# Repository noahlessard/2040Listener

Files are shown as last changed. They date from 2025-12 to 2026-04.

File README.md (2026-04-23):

## 2040Listener

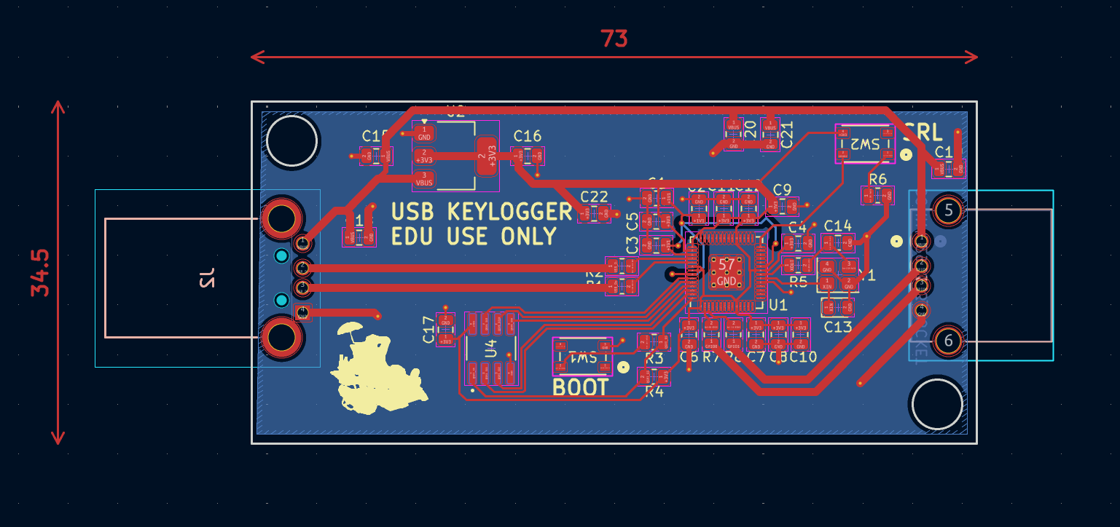
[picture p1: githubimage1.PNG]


This project contains the Raspberry Pi Pico C SDK Project, and Kicad PCB Project, to manufacture an open source MITM style keystroke interceptor. This style of device intercepts a host's computer request to get keystrokes, relays it to a real USB keyboard, and while returning the responses of typed keys, logs it to a LittleFS file stored in flash memory. This memory persists, and can be accessed through a CDC serial port. This port can be toggled on/off for a "stealth" mode.

USB host/device communication is done using the PIO of Raspberry Pi Pico (RP2040). I built the software with the VSCode Pico Project Extension. It uses several other open source libraries, which can be found in the credits section at the bottom of this readme. 

The PCB is designed around the 0805 footprint for easier soldering, and a simple 2 layer board for cheaper manufacturing.

The general idea of the firmware architecture is that core0 of the 2040 acts as a "fake" USB device to the victim computer, sending both HID and CDC data over USB. Core1 acts as a "fake" host stack to a keyboard. Core1 handles getting data from the HID devices, parsing out what the keystroke is and writes to the 2040's LittleFS file before core0 actually transmits. For more details, see my blog post: https://nlessard.online/projects/2040listener/.

**If you decide to build this device yourself, please use it for educational purposes only, and never use it on a computer that you don't control!**

## GPIO 
(This section is useful for testing on a normal Pico board, where access to GP pins is easier.)
|VCC|VBUS|
|-|-|
|D-|GP 1|
|D+|GP 0|
|CNC Toggle|GP 17|
|Ground|GND|

## Credits
Dual host + device listener example from here: https://github.com/brendena/pico_device_and_host, although I used a fork for the Pico VS Code extension: https://github.com/TheLowSpecPC/pico_device_and_host_updated. LittleFS was ported to Pico in this library: https://github.com/tjko/pico-lfs. I used the Raspberry Pi's foundation for a lot of advice during hardware design: https://pip-assets.raspberrypi.com/categories/814-rp2040/documents/RP-008279-DS-1-hardware-design-with-rp2040.pdf

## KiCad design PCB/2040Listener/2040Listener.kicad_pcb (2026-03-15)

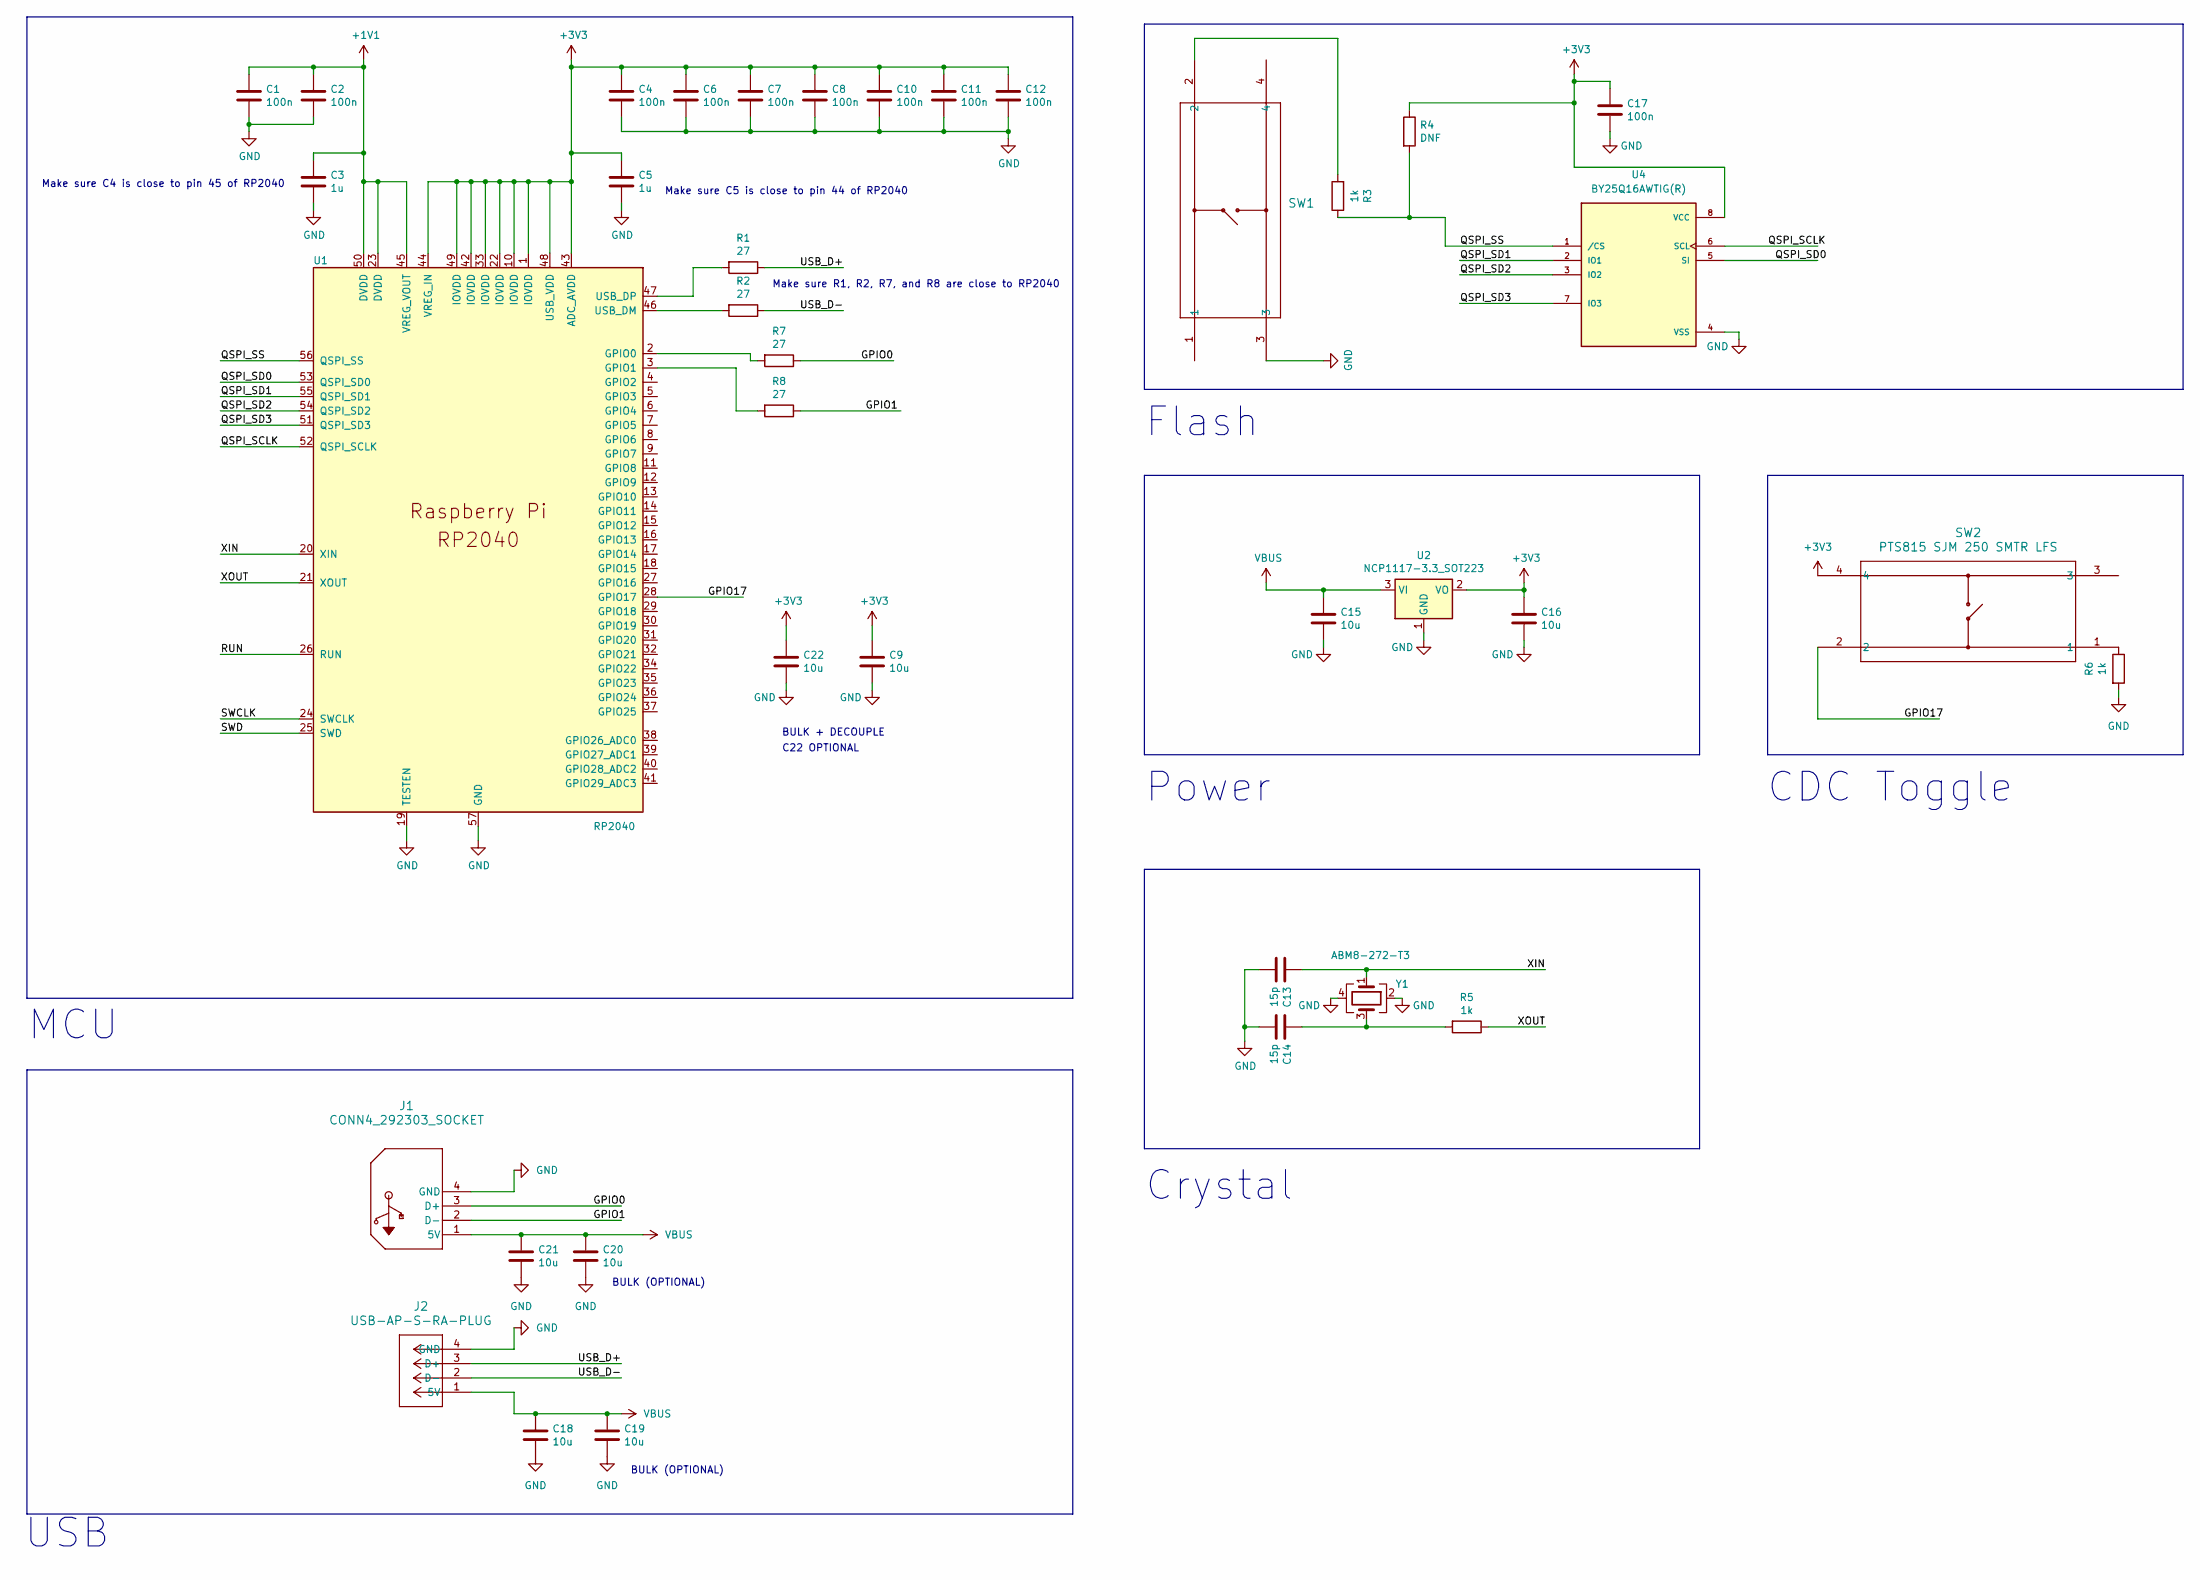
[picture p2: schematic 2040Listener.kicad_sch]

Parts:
C1, C2, C4, C6, C7, C8, C10, C11, C12, C17: 100n; C_0805_2012Metric
C3, C5: 1u; C_0805_2012Metric
C9, C15, C16, C18, C19, C20, C21, C22: 10u; C_0805_2012Metric
C13: 15p; D_0805_2012Metric
C14: 15p; C_0805_2012Metric
J1: CONN4_292303_SOCKET; CONN4_292303_TEC
J2: USB-AP-S-RA-PLUG; CONN_USB-AP-S-RA-SMT_ADM
R1, R2, R7, R8: 27; R_0805_2012Metric
R3, R5, R6: 1k; R_0805_2012Metric
R4: DNF; R_0805_2012Metric
SW1, SW2: PTS815 SJM 250 SMTR LFS; SW4_PTS815 SJM 250 SMTR LFS_CNK
U1: RP2040; RP2040-QFN-56
U2: NCP1117-3.3_SOT223; SOT-223-3_TabPin2
U4: BY25Q16AWTIG(R); SOIC127P600X175-8N
Y1: ABM8-272-T3; Crystal_SMD_3225-4Pin_3.2x2.5mm

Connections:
+1V1: C1.1, C2.1, C3.1, U1.23 (DVDD), U1.45 (VREG_VOUT), U1.50 (DVDD)
+3V3: C4.1, C5.1, C6.1, C7.1, C8.1, C9.1, C10.1, C11.1, C12.1, C16.1, C17.1, C22.1, R4.1, SW2.4, U1.1 (IOVDD), U1.10 (IOVDD), U1.22 (IOVDD), U1.33 (IOVDD), U1.42 (IOVDD), U1.43 (ADC_AVDD), U1.44 (VREG_IN), U1.48 (USB_VDD), U1.49 (IOVDD), U2.2 (VO), U4.8 (VCC)
/GPIO0: J1.3 (D+), R7.1
/GPIO1: J1.2 (D-), R8.1
/GPIO17: SW2.2, U1.28 (GPIO17)
/QSPI_SCLK: U1.52 (QSPI_SCLK), U4.6 (SCL)
/QSPI_SD0: U1.53 (QSPI_SD0), U4.5 (SI)
/QSPI_SD1: U1.55 (QSPI_SD1), U4.2 (IO1)
/QSPI_SD2: U1.54 (QSPI_SD2), U4.3 (IO2)
/QSPI_SD3: U1.51 (QSPI_SD3), U4.7 (IO3)
/QSPI_SS: R3.1, R4.2, U1.56 (QSPI_SS), U4.1 (/CS)
/RUN: U1.26 (RUN)
/SWCLK: U1.24 (SWCLK)
/SWD: U1.25 (SWD)
/USB_D+: J2.3 (D+), R1.1
/USB_D-: J2.2 (D-), R2.1
/XIN: C13.1, U1.20 (XIN), Y1.1
/XOUT: R5.1, U1.21 (XOUT)
GND: C1.2, C2.2, C3.2, C4.2, C5.2, C6.2, C7.2, C8.2, C9.2, C10.2, C11.2, C12.2, C13.2, C14.2, C15.2, C16.2, C17.2, C18.2, C19.2, C20.2, C21.2, C22.2, J1.4 (GND), J2.4 (GND), R6.2, SW1.3, U1.19 (TESTEN), U1.57 (GND), U2.1 (GND), U4.4 (VSS), Y1.2, Y1.4
unnamed: C14.1, R5.2, Y1.3
unnamed: R3.2, SW1.2
unnamed: R6.1, SW2.1
unnamed: R7.2, U1.2 (GPIO0)
unnamed: R8.2, U1.3 (GPIO1)
unnamed: R2.2, U1.46 (USB_DM)
unnamed: R1.2, U1.47 (USB_DP)
VBUS: C15.1, C18.1, C19.1, C20.1, C21.1, J1.1 (5V), J2.1 (5V), U2.3 (VI)

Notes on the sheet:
Power
BULK (OPTIONAL)
USB
C22 OPTIONAL
Make sure C5 is close to pin 44 of RP2040
Make sure R1, R2, R7, and R8 are close to RP2040
BULK + DECOUPLE
CDC Toggle
Crystal
Flash
MCU
Make sure C4 is close to pin 45 of RP2040

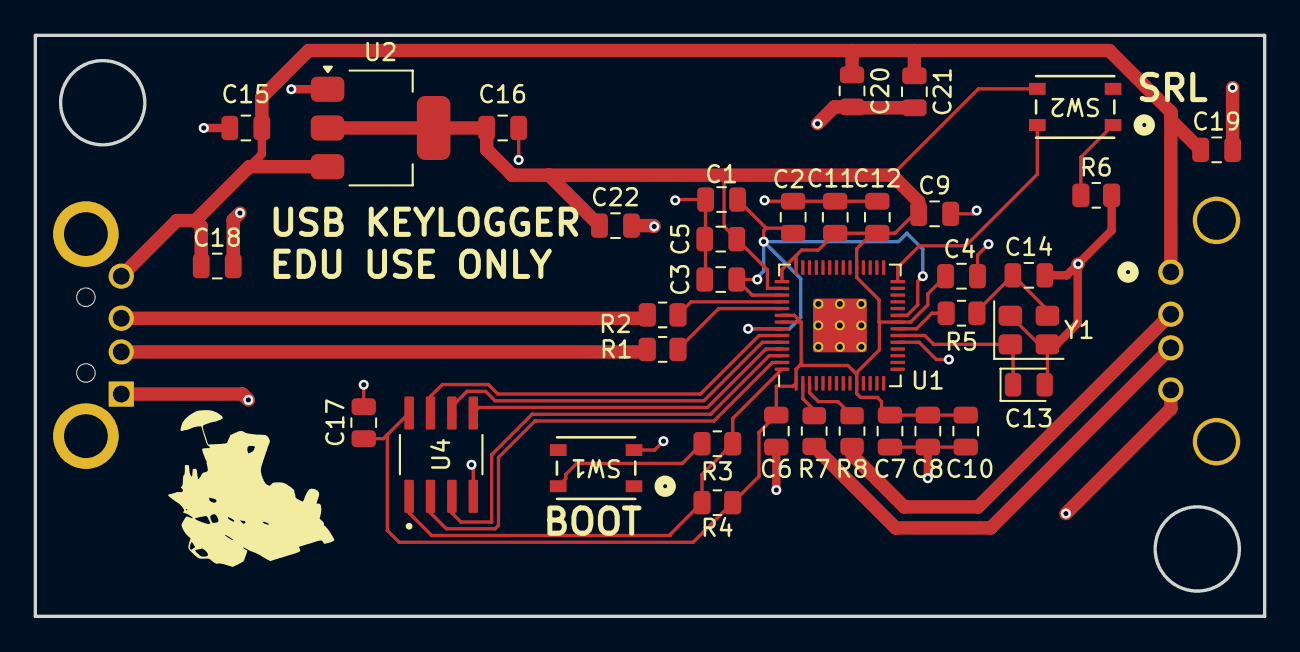
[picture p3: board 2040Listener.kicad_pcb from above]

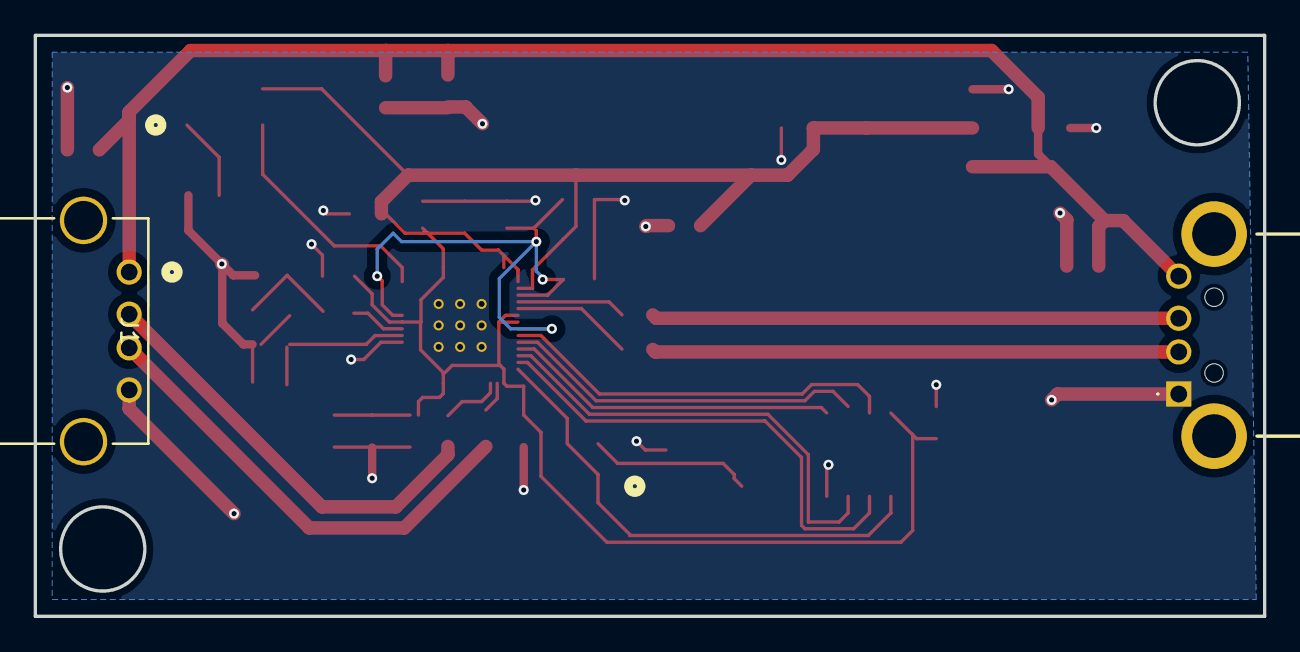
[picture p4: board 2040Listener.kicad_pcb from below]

Board: 2 copper layers, 73.0 x 34.5 mm, 38 parts (2 on the bottom side), 24 nets.

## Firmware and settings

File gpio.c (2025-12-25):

#include "hardware/gpio.h"
#include "pinconfig.h"
#include "tusb.h"

// the default behavior upon start up depends on this
bool cdc_enabled = false;
bool button_pressed = false;

void setup_cdc_mode()
{
  gpio_init(PIN_STEALTH_MODE);
  gpio_set_dir(PIN_STEALTH_MODE, GPIO_IN);
  gpio_pull_down(PIN_STEALTH_MODE);
}

void check_cdc_mode()
{ 
  bool current_pin_state = gpio_get(PIN_STEALTH_MODE);
  
  // detect rising edge, don't trigger
  if (current_pin_state == 1 && !button_pressed) {
    button_pressed = true;
  }
  // detect falling edge, trigger and reconnect
  else if (current_pin_state == 0 && button_pressed) {
    button_pressed = false;
    cdc_enabled = !cdc_enabled;
    
    tud_disconnect();
    sleep_ms(1500);
    tud_connect();
  }
}

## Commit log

2025-12-25 correct toggle func, readme update
    [gpio.c]
2025-12-29 start kicad
    [2040Listener.kicad_pcb, 2040Listener.kicad_sch]
2025-12-29 change to 0805
    [2040Listener.kicad_sch]
2025-12-30 update pcb, symbols
    [2040Listener.kicad_sch]
2026-01-01 reposition elements for better routing
    [2040Listener.kicad_pcb, 2040Listener.kicad_sch]
2026-01-01 first gerber
    [2040Listener-B_Cu.gbr, 2040Listener-B_Mask.gbr, 2040Listener-B_Paste.gbr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]
2026-01-01 fix small footprint
    [2040Listener-B_Cu.gbr, 2040Listener-B_Mask.gbr, 2040Listener-B_Paste.gbr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]
2026-01-03 update schematic text
    [2040Listener.kicad_sch]
2026-02-13 attempt to fix usb connector
    [2040Listener-B_Cu.gbr, 2040Listener-B_Mask.gbr, 2040Listener-B_Paste.gbr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]
2026-03-05 flip usb plugs
    [2040Listener.kicad_pcb]
2026-03-12 pcb works!
    [2040Listener-B_Cu.gbr, 2040Listener-B_Mask.gbr, 2040Listener-B_Paste.gbr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]
2026-03-15 update pcb spacing
    [2040Listener-B_Cu.gbr, 2040Listener-B_Mask.gbr, 2040Listener-B_Paste.gbr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]
2026-03-16 update pcb image
